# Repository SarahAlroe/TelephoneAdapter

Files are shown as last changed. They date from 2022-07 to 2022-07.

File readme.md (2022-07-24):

# TelephoneAdapter

Circuits and prints to let you use a landline (presumably carbon microphone) telephone as a microphone.
More info [here](http://sarah.alroe.dk/2022/TelephoneAdapter/).

One directory is for a phantom powered adapter. The other is for one with externally supplied power.

To produce an adapter without modification, print the stl parts from that folder, print and etch the corresponding circut, solder and assemble.
The root directory pdf contains a ready to print and mask set of positives for both circuits.

BOMs with suggested component sources follows:

Phantom Power BOM:

* 1 Generic 1/4W resistor of a couple hundred ohms
* 1 22 µF capacitor (ceramic or similar)
* 1 200 µF capacitor (electrolytic)
* 2 Zener diodes (5.1V or there about)
* 1 600:600 transformer with center tap eg. [42TL016-RC](https://www.aliexpress.com/wholesale?SearchText=42TL016-RC)
* 1 XLR plug eg. [from R connector](https://www.aliexpress.com/item/4000563708302.html)
* 1 Telephone plug eg. [this](https://elektronik-lavpris.dk/p125084/telstik-hun-wh-telefonstik-hun-hvid/), though check your local charity shop first.
* 6 M3x16 bolts
* 4 M3X40 bolts
* 10 M3 Nuts
* All 3D printed parts

External Power BOM:

* 1 Generic 1/4W resistor of a couple hundred ohms
* 1 22 µF capacitor (ceramic or similar)
* 1 200 µF capacitor (electrolytic)
* 2 Zener diodes (5.1V or there about)
* 1 600:600 isolation transformer eg. [EI14](https://www.aliexpress.com/wholesale?SearchText=EI14)
* 1 Telephone plug eg. [this](https://elektronik-lavpris.dk/p125084/telstik-hun-wh-telefonstik-hun-hvid/), though check your local charity shop first.
* 4 M3x16 bolts
* 4 M3X40 bolts
* 8 M3 Nuts
* All 3D printed parts

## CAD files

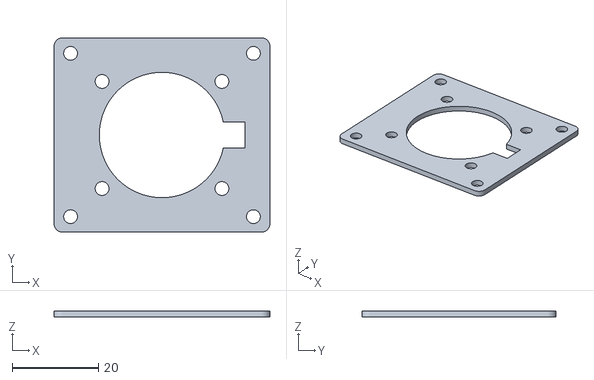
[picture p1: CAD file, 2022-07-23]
TAExternalPower/TAEP Lid.stl
50.0 x 45.0 x 1.50

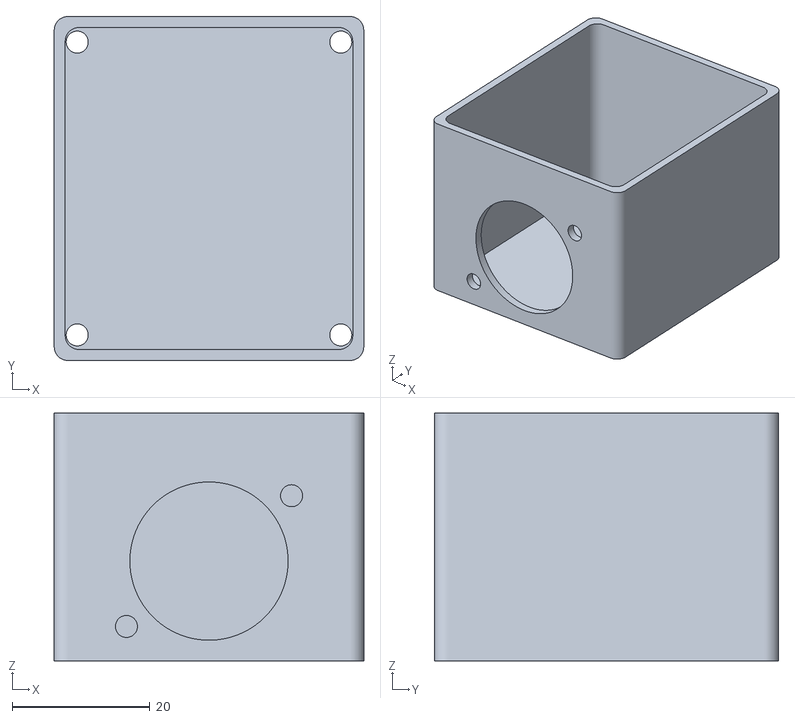
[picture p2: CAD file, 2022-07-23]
TAPhantomPower/TAPP Case.stl
45.0 x 50.0 x 36.0

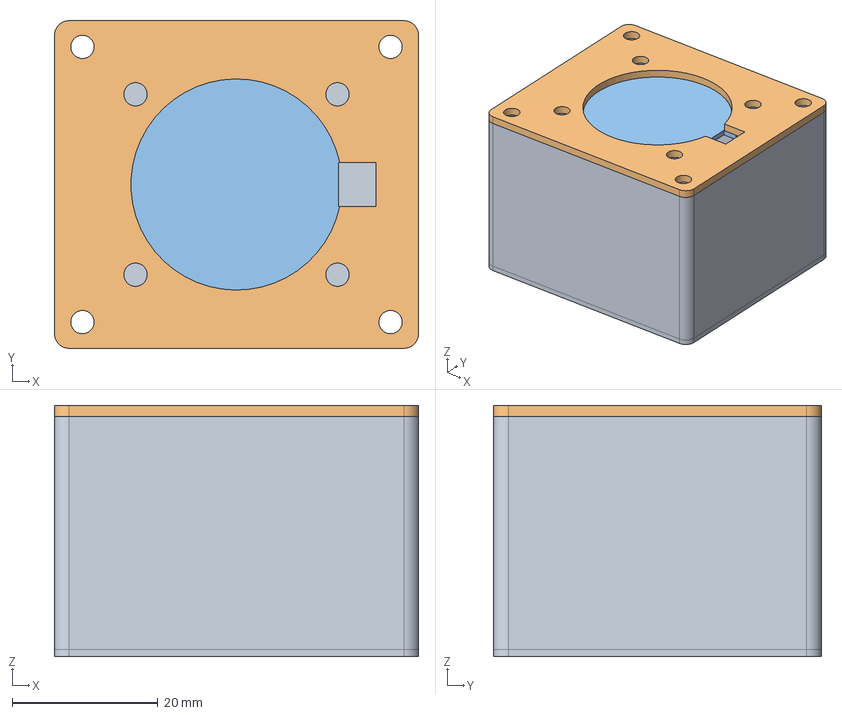
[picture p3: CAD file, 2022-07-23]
TAExternalPower/TAExternalPowerCase.FCStd
50.0 x 45.0 x 34.5 mm
Case
Lid
SocketHolder

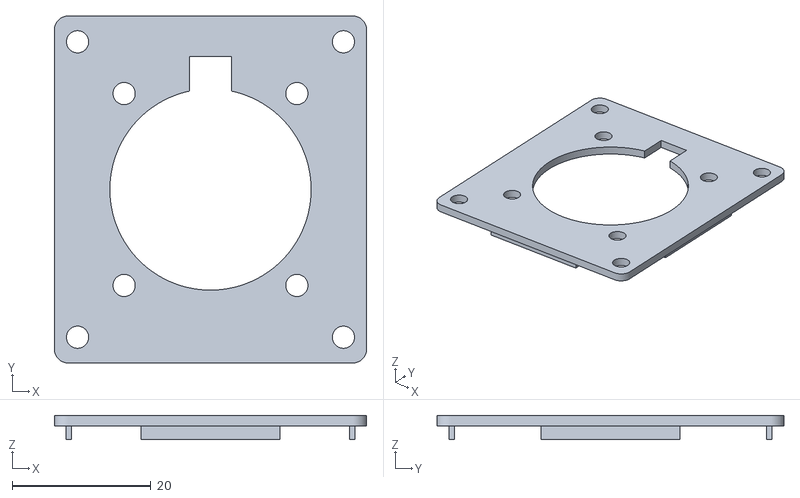
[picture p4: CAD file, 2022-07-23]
TAPhantomPower/TAPP Lid.stl
45.0 x 50.0 x 3.50

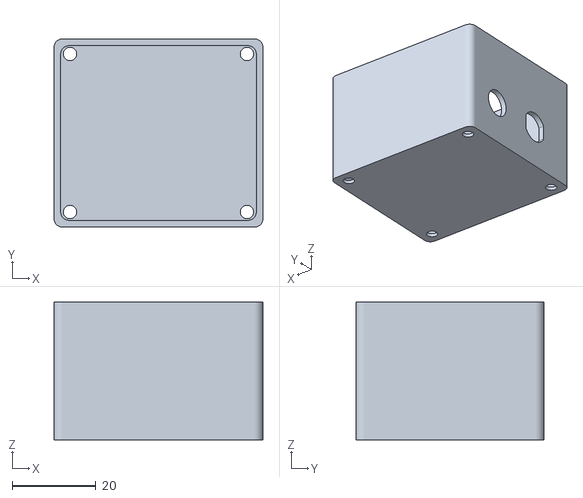
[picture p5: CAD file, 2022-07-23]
TAExternalPower/TAEP Case.stl
50.0 x 45.0 x 33.0

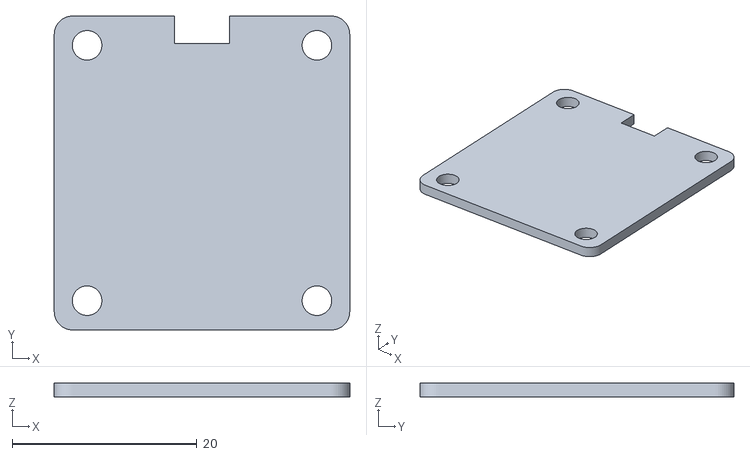
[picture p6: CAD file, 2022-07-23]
TAPhantomPower/TAPP SocketHolder.stl
32.0 x 34.0 x 1.50

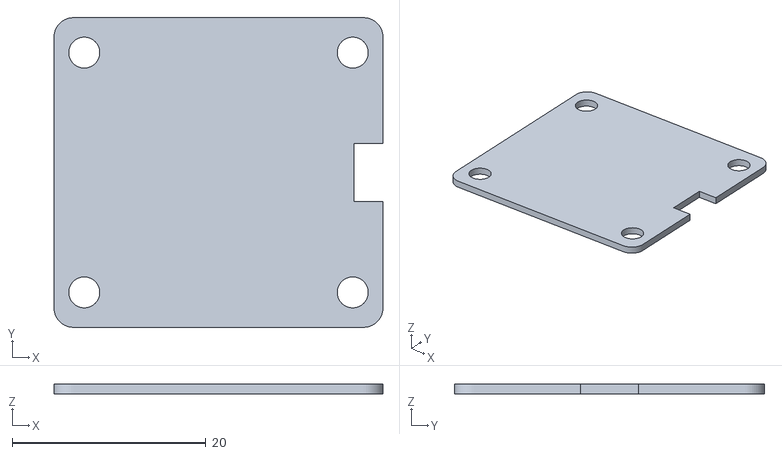
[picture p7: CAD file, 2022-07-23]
TAExternalPower/TAEP SocketHolder.stl
34.0 x 32.0 x 1.00

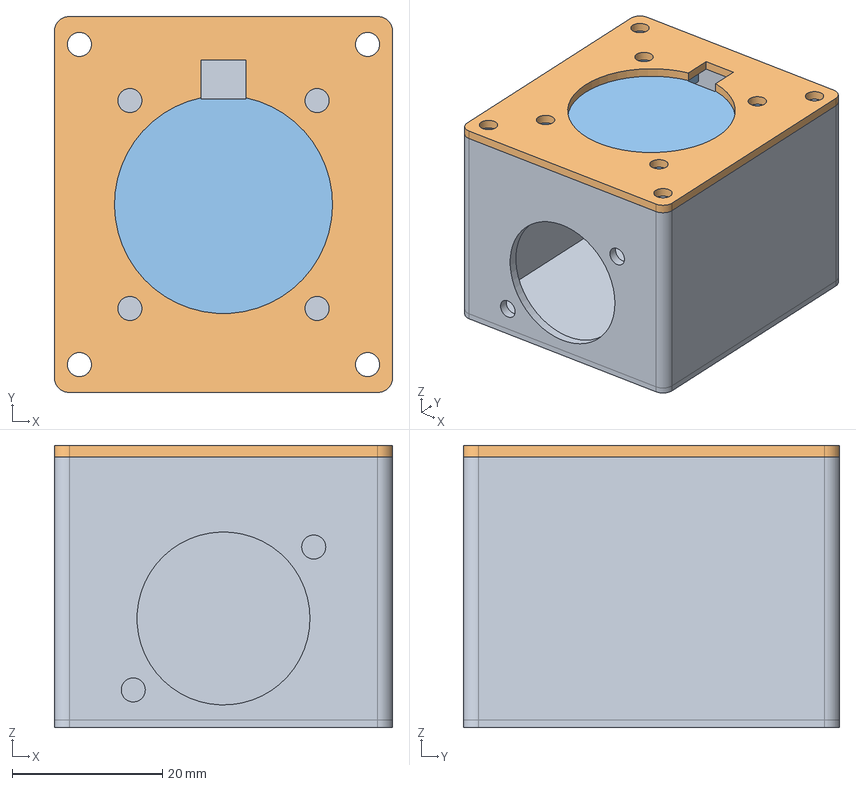
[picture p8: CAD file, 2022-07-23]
TAPhantomPower/TAPhantomPowerCase.FCStd
45.0 x 50.0 x 37.5 mm
Case
Lid
SocketHolder

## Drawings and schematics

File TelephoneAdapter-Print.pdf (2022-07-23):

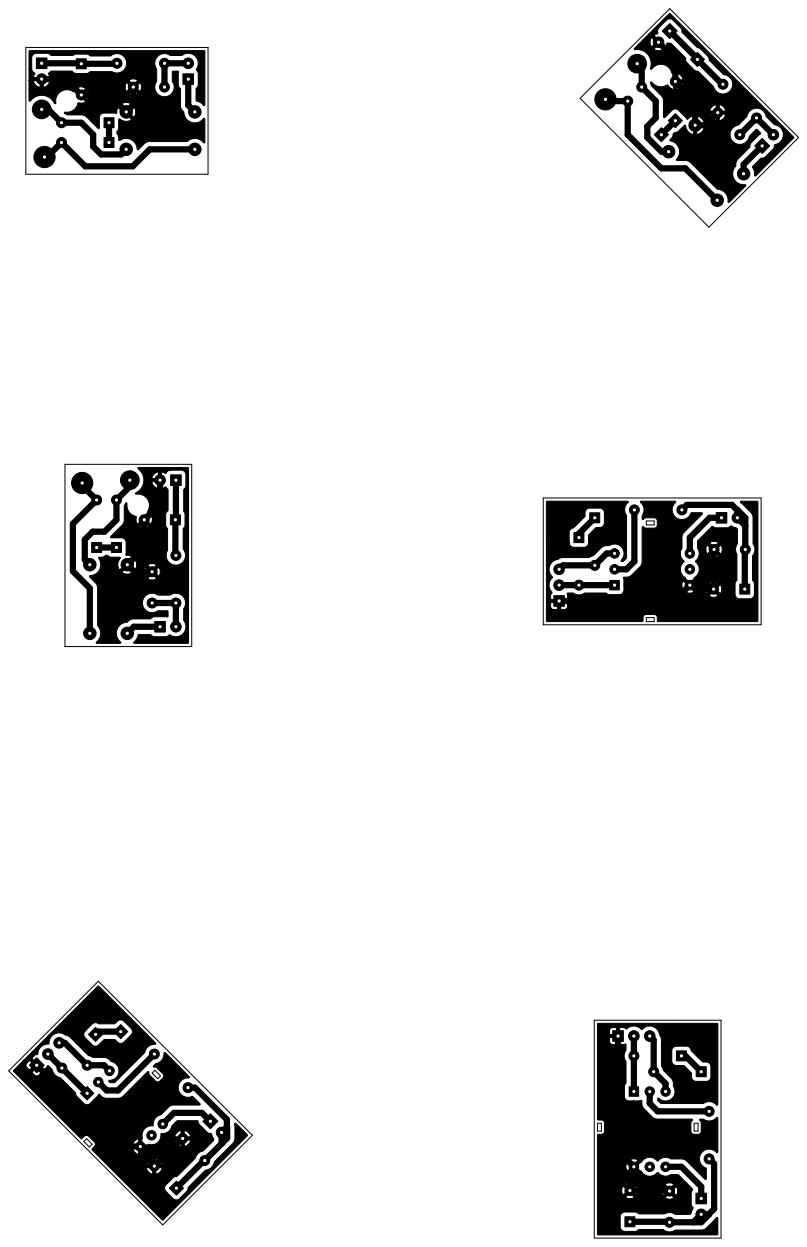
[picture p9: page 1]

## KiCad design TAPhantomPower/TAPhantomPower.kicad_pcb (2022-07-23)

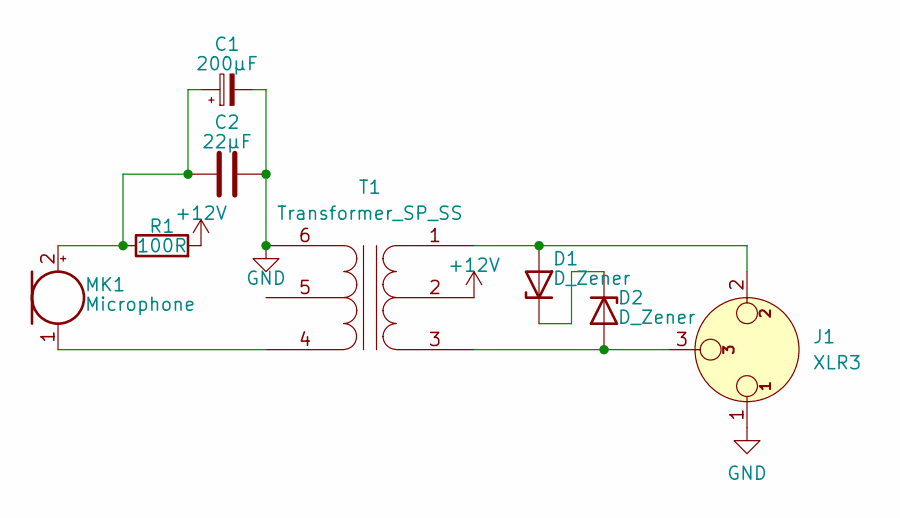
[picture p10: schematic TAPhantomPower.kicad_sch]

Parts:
C1: 200µF; CP_Radial_D8.0mm_P5.00mm
C2: 22µF; C_Disc_D4.7mm_W2.5mm_P5.00mm
D1, D2: D_Zener; D_DO-35_SOD27_P7.62mm_Horizontal
J1: XLR3; PinHeader_1x03_P2.54mm_Vertical
MK1: Microphone; PinHeader_1x02_P2.54mm_Vertical
R1: 100R; R_Axial_DIN0207_L6.3mm_D2.5mm_P7.62mm_Horizontal
T1: Transformer_SP_SS; Transformer_42TL

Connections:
+12V: R1.2, T1.2 (AC)
GND: C1.2, C2.2, J1.1, T1.6 (SB)
unnamed: C1.1, C2.1, MK1.2 (+), R1.1
unnamed: D1.1 (K), D2.1 (K)
unnamed: D1.2 (A), J1.2, T1.1 (AA)
unnamed: D2.2 (A), J1.3, T1.3 (AB)
unnamed: MK1.1 (-), T1.4 (SA)

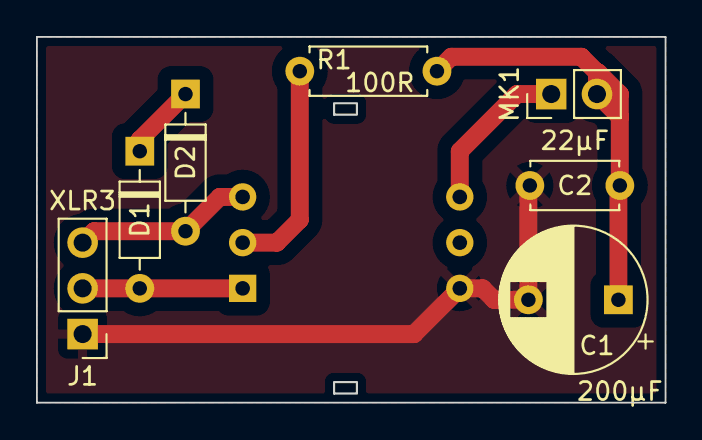
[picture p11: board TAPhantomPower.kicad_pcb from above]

Board: 2 copper layers, 34.9 x 20.3 mm, 8 parts (1 on the bottom side), 7 nets.

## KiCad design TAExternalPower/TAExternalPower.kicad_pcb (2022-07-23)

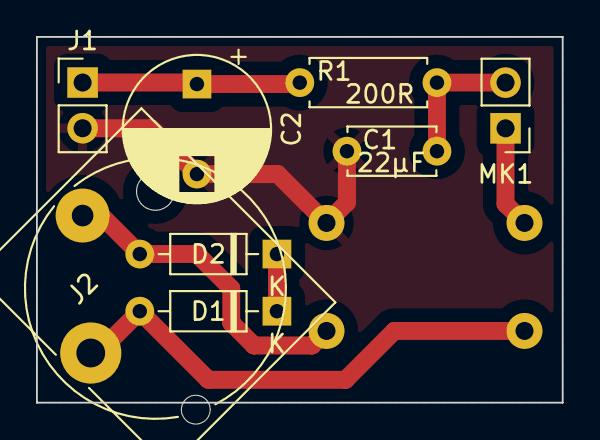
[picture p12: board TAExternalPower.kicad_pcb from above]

Board: 2 copper layers, 29.2 x 20.3 mm, 9 parts (1 on the bottom side), 7 nets.

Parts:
C1: 22µF; C_Disc_D4.7mm_W2.5mm_P5.00mm
C2: 200µF; CP_Radial_D8.0mm_P5.00mm
D1, D2: D_Zener; D_DO-35_SOD27_P7.62mm_Horizontal
J1: Barrel_Jack; PinHeader_1x02_P2.54mm_Vertical
J2: AudioJack2_Ground; Jack_6.35mm_Neutrik_NJ2FD-V_Vertical
MK1: Microphone; PinHeader_1x02_P2.54mm_Vertical
R1: 200R; R_Axial_DIN0207_L6.3mm_D2.5mm_P7.62mm_Horizontal
T1: Transformer_1P_1S; Transformer_Toroid_Horizontal_D9.0mm_Amidon-T30

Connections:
+12V: C2.1, J1.1, R1.2
GND: C1.2, C2.2, J1.2, T1.1 (AA)
unnamed: C1.1, MK1.2 (+), R1.1
unnamed: D1.1 (K), D2.1 (K)
unnamed: D1.2 (A), J2.S, T1.4 (SB)
unnamed: D2.2 (A), J2.T, T1.3 (SA)
unnamed: MK1.1 (-), T1.2 (AB)
